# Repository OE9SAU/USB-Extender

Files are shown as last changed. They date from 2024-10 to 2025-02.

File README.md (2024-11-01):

# USB Extender

CH315G is a USB extension control chip, used for USB signal real time transmit and extend transfer distance.
The USB signal extension circuit in the CH315G, support category 5 or category 5 unshielded twisted-pair cables, 
and the transfer distance is no less than 75m of 12Mbps full-speed USB signal, the transfer distance is no less than 300m of 1.5Mbps.

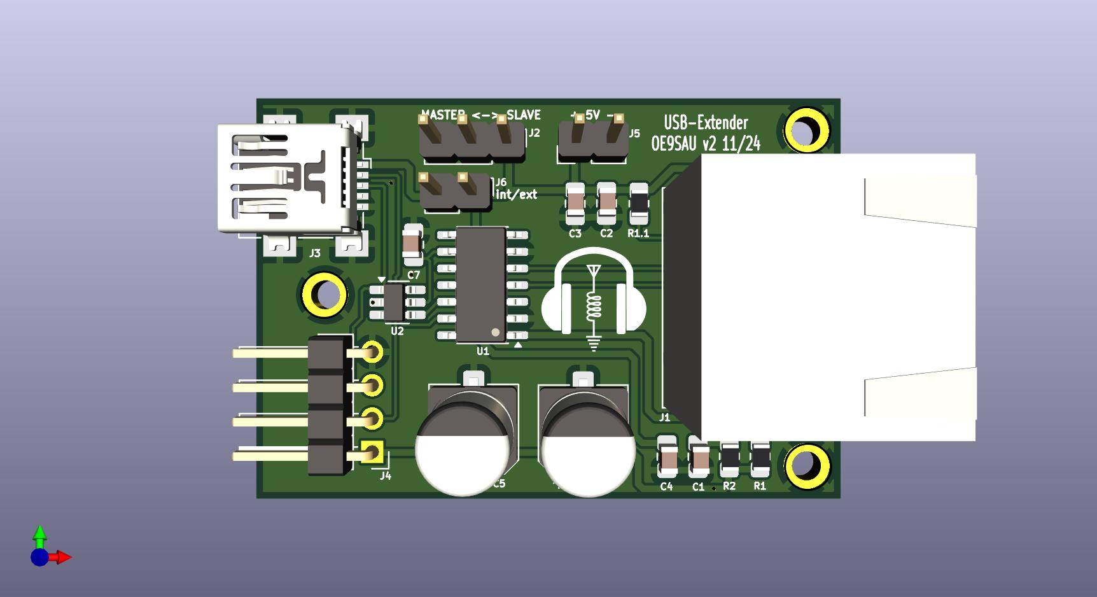
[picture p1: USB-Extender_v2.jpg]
USB-Extender-V1


v2: 
* wrong footprint for USBLC6-2 (SOT666->SOT23-6)
* add R1.1 LED choice for RJ45 plug
* wrong marking SLAVE<->MASTER, new: MASTER<->SLAVE

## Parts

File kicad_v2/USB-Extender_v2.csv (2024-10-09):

ID | Bezeichner | Footprint | Stückzahl | Bezeichnung | Anbieter und Referenz
1 | C2,C1,C4,C3 | C_0805_2012Metric_Pad1.18x1.45mm_HandSolder | 4 | 100nF
2 | J5 | PinHeader_1x02_P2.54mm_Vertical | 1 | ext. +5V
3 | J4 | PinHeader_1x04_P2.54mm_Horizontal | 1 | USB_CON
4 | C6,C5 | CP_Elec_6.3x7.7 | 2 | 470uF
5 | R1 | R_0805_2012Metric_Pad1.20x1.40mm_HandSolder | 1 | 10k
6 | R3 | R_0805_2012Metric_Pad1.20x1.40mm_HandSolder | 1 | 180k
7 | J3 | USB_Mini-B_Wuerth_65100516121_Horizontal | 1 | USB_B_Mini
8 | U1 | SOIC-14_3.9x8.7mm_P1.27mm | 1 | CH315G
9 | J2 | PinHeader_1x03_P2.54mm_Vertical | 1 | MODE
10 | J1 | RJ45_Amphenol_RJHSE538X | 1 | RJ45_LED_Shielded

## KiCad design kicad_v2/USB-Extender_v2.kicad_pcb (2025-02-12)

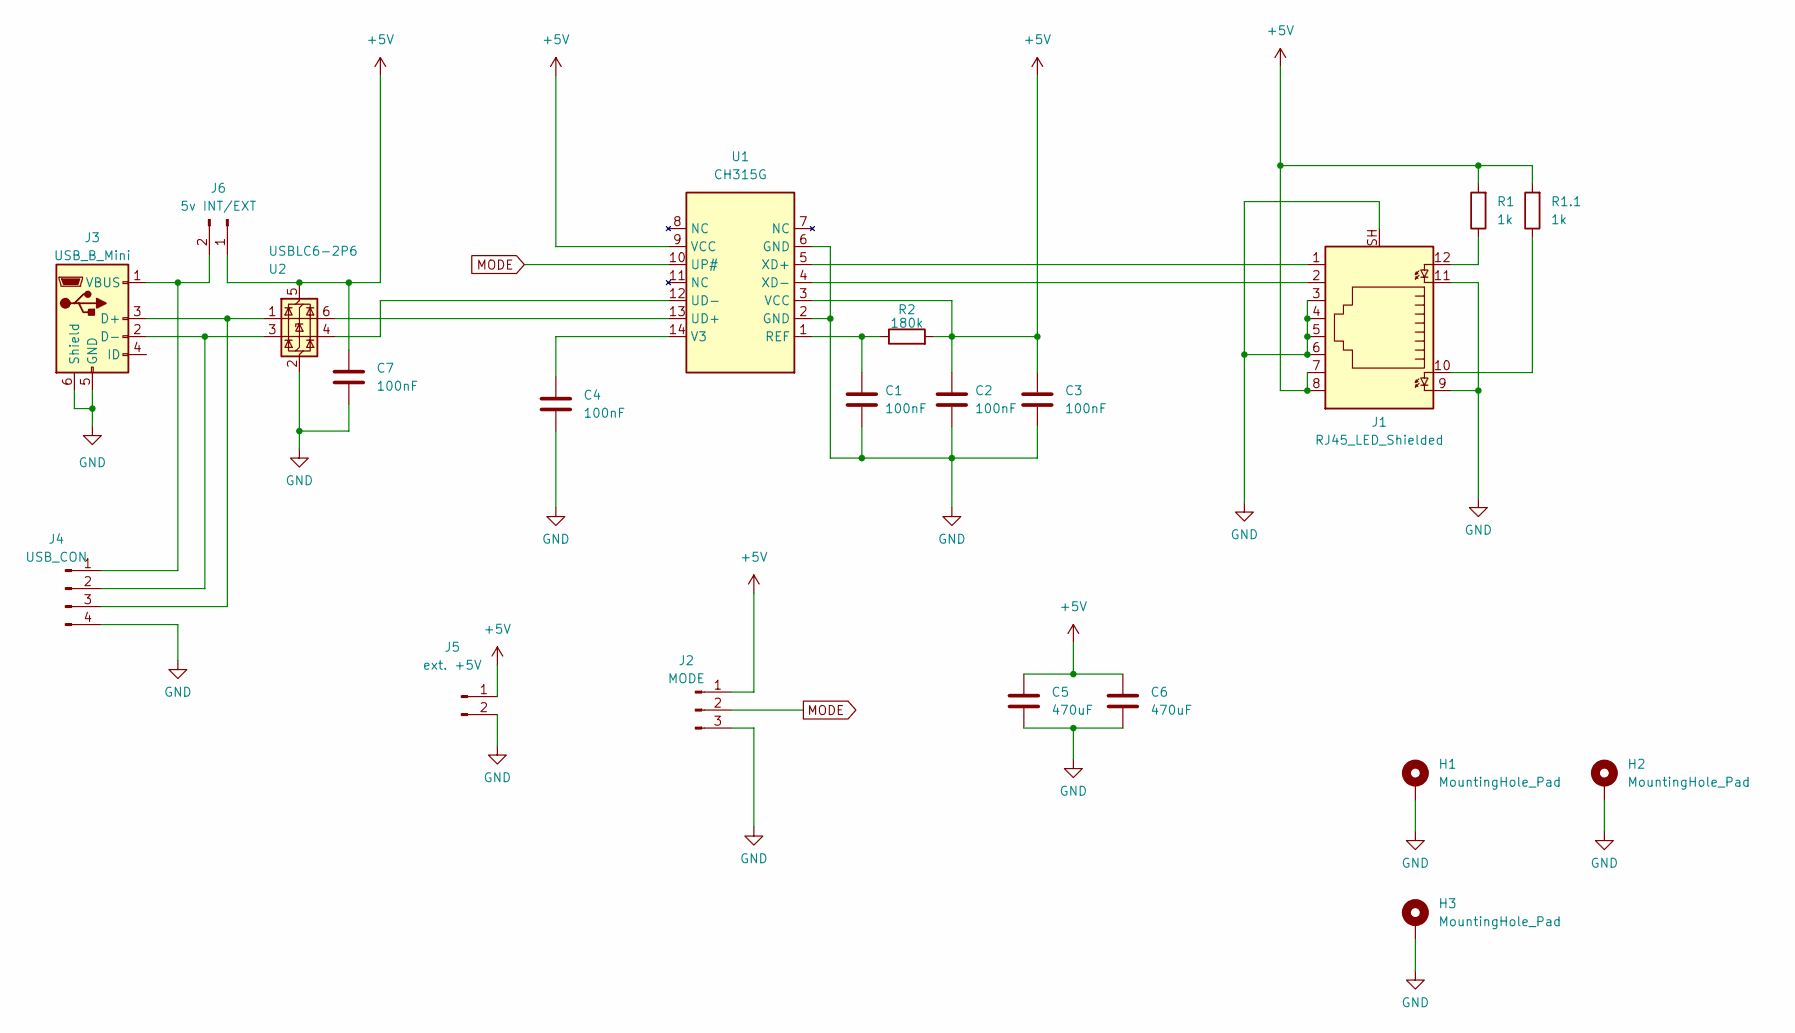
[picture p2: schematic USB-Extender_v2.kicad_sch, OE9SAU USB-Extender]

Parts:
C1, C2, C3, C4, C7: 100nF; C_0805_2012Metric_Pad1.18x1.45mm_HandSolder
C5, C6: 470uF; CP_Elec_6.3x7.7
H1, H2, H3: MountingHole_Pad; MountingHole_2.2mm_M2_ISO7380_Pad
J1: RJ45_LED_Shielded; RJ45_Amphenol_RJHSE538X
J2: MODE; PinHeader_1x03_P2.54mm_Vertical
J3: USB_B_Mini; USB_Mini-B_Wuerth_65100516121_Horizontal
J4: USB_CON; PinHeader_1x04_P2.54mm_Horizontal
J5: ext. +5V; PinHeader_1x02_P2.54mm_Vertical
J6: 5v INT/EXT; PinHeader_1x02_P2.54mm_Vertical
R1, R1.1: 1k; R_0805_2012Metric_Pad1.20x1.40mm_HandSolder
R2: 180k; R_0805_2012Metric_Pad1.20x1.40mm_HandSolder
U1: CH315G; SOIC-14_3.9x8.7mm_P1.27mm
U2: USBLC6-2P6; SOT-23-6_Handsoldering

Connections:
+5V: C2.1, C3.1, C5.1, C6.1, C7.1, J1.7, J1.8, J2.1, J5.1, J6.1, R1.2, R1.1.2, R2.2, U1.3 (VCC), U1.9 (VCC), U2.5 (VBUS)
GND: C1.2, C2.2, C3.2, C4.2, C5.2, C6.2, C7.2, H1.1, H2.1, H3.1, J1.3, J1.4, J1.5, J1.6, J1.9, J1.11, J1.SH, J2.3, J3.5 (GND), J3.6 (Shield), J4.4, J5.2, U1.2 (GND), U1.6 (GND), U2.2 (GND)
MODE: J2.2, U1.10 (UP#)
unnamed: J1.10, R1.1.1
unnamed: J1.12, R1.1
unnamed: J3.3 (D+), J4.3, U2.1 (I/O1)
unnamed: J3.2 (D-), J4.2, U2.3 (I/O2)
unnamed: J3.1 (VBUS), J4.1, J6.2
unnamed: C1.1, R2.1, U1.1 (REF)
unnamed: U1.13 (UD+), U2.6 (I/O1)
unnamed: U1.12 (UD-), U2.4 (I/O2)
unnamed: C4.1, U1.14 (V3)
unnamed: J1.1, U1.5 (XD+)
unnamed: J1.2, U1.4 (XD-)

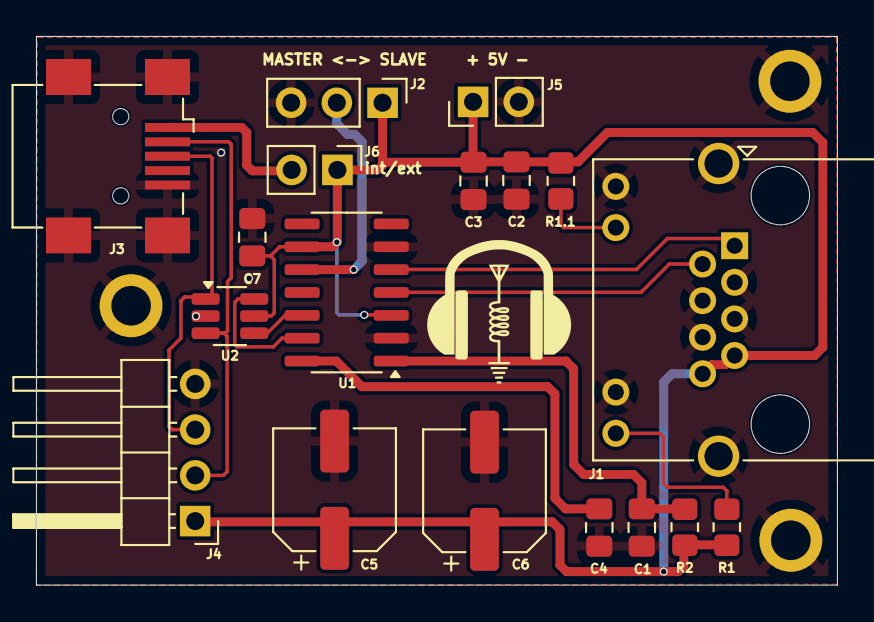
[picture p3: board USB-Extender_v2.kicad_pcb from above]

Board: 2 copper layers, 44.5 x 30.5 mm, 23 parts (1 on the bottom side), 14 nets.

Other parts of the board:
g1, g2: LOGO

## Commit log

2024-10-09 Update V1
    [USB-Extender_v1-B_Cu.gbr, USB-Extender_v1-B_Mask.gbr, USB-Extender_v1-B_Paste.gbr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]
2024-10-10 Update vias
    [USB-Extender_v1-B_Cu.gbr, USB-Extender_v1-B_Mask.gbr, USB-Extender_v1-B_Paste.gbr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]
2024-10-10 Update Number
    [USB-Extender_v1-B_Cu.gbr, USB-Extender_v1-B_Mask.gbr, USB-Extender_v1-B_Paste.gbr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]
2024-11-01 PCB v2
    Footprint change
    [USB-Extender_v1.csv, USB-Extender_v1.dsn, USB-Extender_v1.kicad_pcb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]
2024-11-01 Update v2
    [USB-Extender_v1.kicad_sch, USB-Extender_v2.kicad_pcb, USB-Extender_v2.kicad_sch]
